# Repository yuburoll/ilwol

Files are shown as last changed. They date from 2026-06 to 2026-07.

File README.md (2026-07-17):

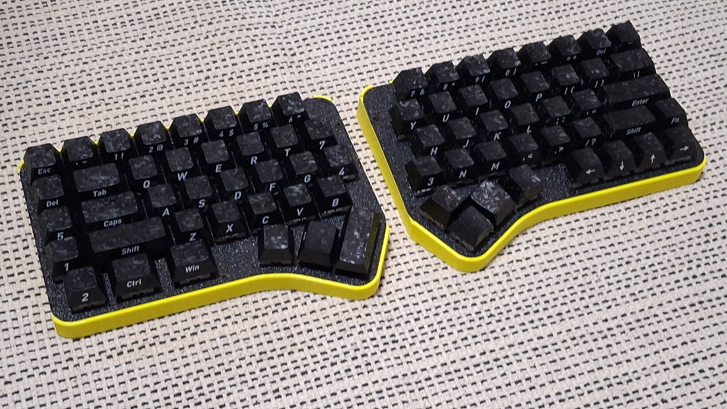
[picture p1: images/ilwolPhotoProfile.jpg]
ilwol


# ilwol
row staggered 60% hotswappable keyboard with reversible PCB, sibling of [phalwol](https://github.com/yuburoll/phalwol)

The name ilwol is January in Korean.

This keyboard has additional Y/H/B keys which positioned between keyboards, and auxilary row at left outside. You may put the keycaps from numpad.

This keyboard has hotswap-only PCB.

ilwol can change layout to followings:

- Split left shift, to ISO shaped one.(2.25u to 1.25u/1u)

- Split right shift, to HHKB inspired shape.(2.75u to 1.75u/1u)

- Split outside thumb keys(2u to 1u/1u)

- Split backspace(2u to 1u/1u)

- Can use stepped caps lock

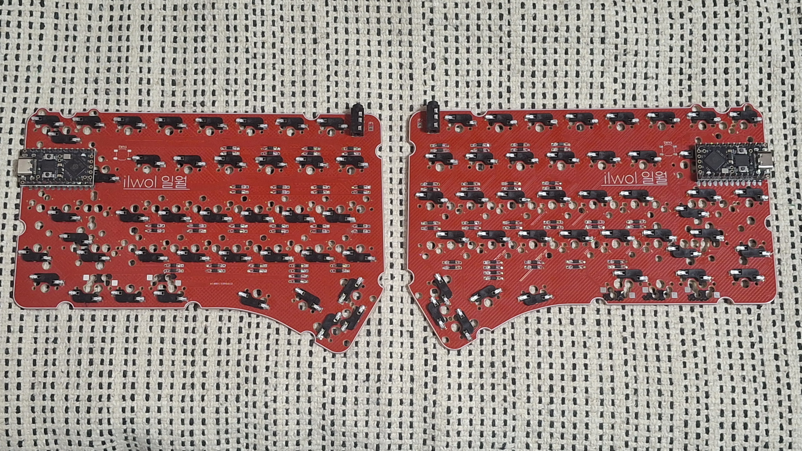
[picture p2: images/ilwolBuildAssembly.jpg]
ilwolBuildAssembly


## Preparation

- 2x pro micro form factor dev board

- 2x ilwol PCB Boards, provided from the repo

- 1x printed case sets, 2 parts total, provided from the repo (for thicker case, use "Buffed". want more? use "roundBuffed")

- 1x 1.5-1.6T keyboard plate sets, 2 parts total, provided from the repo

- 80x diodes, normally 1N4148

- 84x Kailh hotswap sockets (or compatibles)

- 16x M2x6 screws, flathead

- 2x PJ320A 1/8(3.5mm) TRRS connector (MJ-4PP-9 in other name)

- 2x 4x4x1.5mm surface mount tact switches (optional, for dev boards without reset button)

- 1x 1/8(3.5mm) TRRS cable

- 1-6x PCB Mounted 2u Keyboard Stabilizers, normally 6

- 73-78x MX Keyswitches, normally 73

- 8x 10mm bumpon stickers

- A set of Keycaps, Full-size layout, ANSI preferred.

## Differences between case variations

|Original|Buffed|RoundBuffed|Frame|
|:---:|:---:|:---:|:---:|
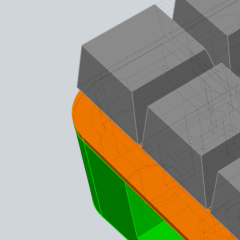
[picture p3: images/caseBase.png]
Base
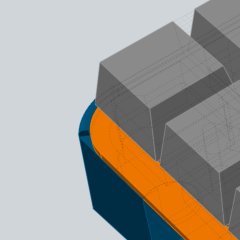
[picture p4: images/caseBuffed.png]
Buff
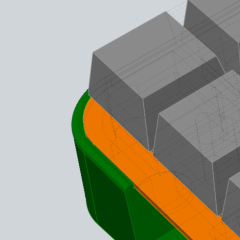
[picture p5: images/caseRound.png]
Round
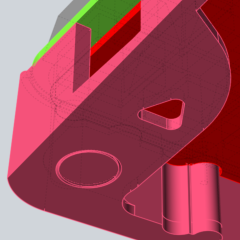
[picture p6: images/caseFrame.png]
Frame
|||||

(Frame case are lightest option for 3d print, but it is very brittle)

## Build Guides and Miscellaneous

[ilwol Build Guide](docs/buildGuide.md)

there's some notices before the build:

- You may solder all hotswaps before soldering the dev board.

- Assemble dev board with 2.5mm height pin headers on back side, assume that components side are faced up.

- Jump every jumpers on front side.

[Additional Tenting Stand](https://github.com/yuburoll/yubuGadgets/tree/main/phalilwolTentingStand)

Also take a look at the sibling, [phalwol](https://github.com/yuburoll/phalwol).

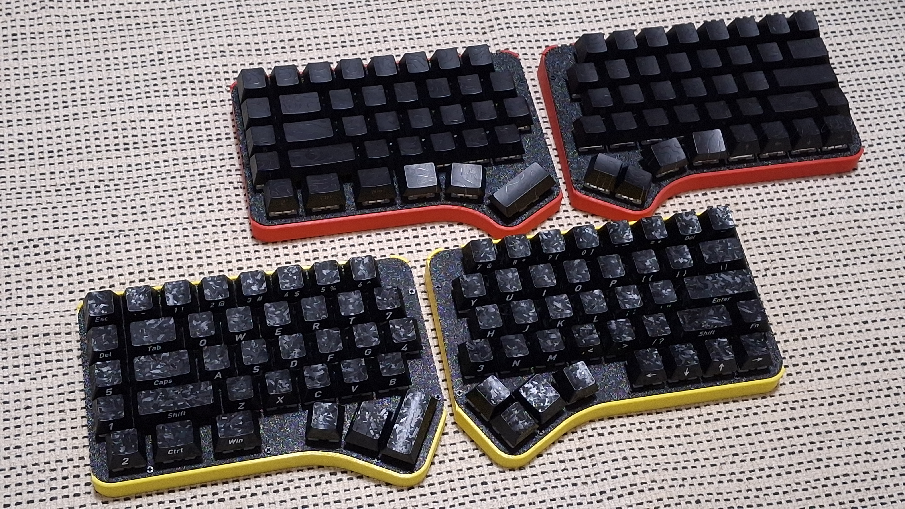
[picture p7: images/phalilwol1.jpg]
phalilwol


## Sponsorship Notice

This project is sponsored by [PCBway](https://www.pcbway.com/), where I ordered prototype PCB.

Their detailed reviewing service was fast and great. I think it will be worth the money for commercial prototyping.

And, they provide complex options (like matte coating on PCB, which pretty surprised me) for both PCB and PCBA, which are necessary for some high-end, important projects.

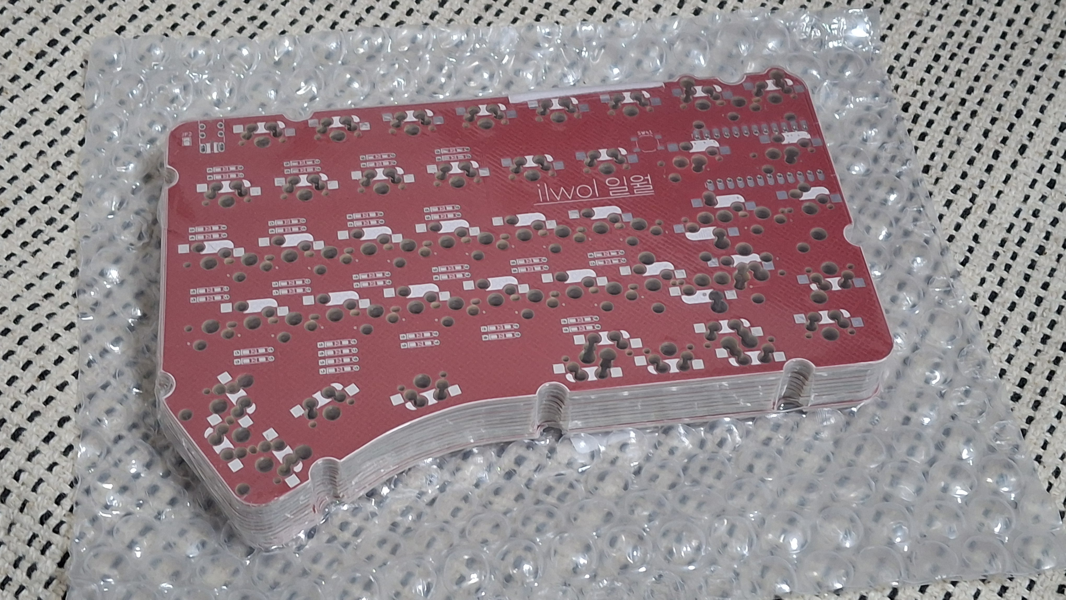
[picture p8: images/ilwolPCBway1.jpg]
ilwolPCBway1


## Licenses

all codes follow MIT license.

all designs and the hardware board follow CC BY-SA 4.0 license.

Markdown documents and photos in docs/images folder are copyrighted, all rights reserved.

If you want to make a commercial product, it would be appreciated if you sponsor some bucks for me.

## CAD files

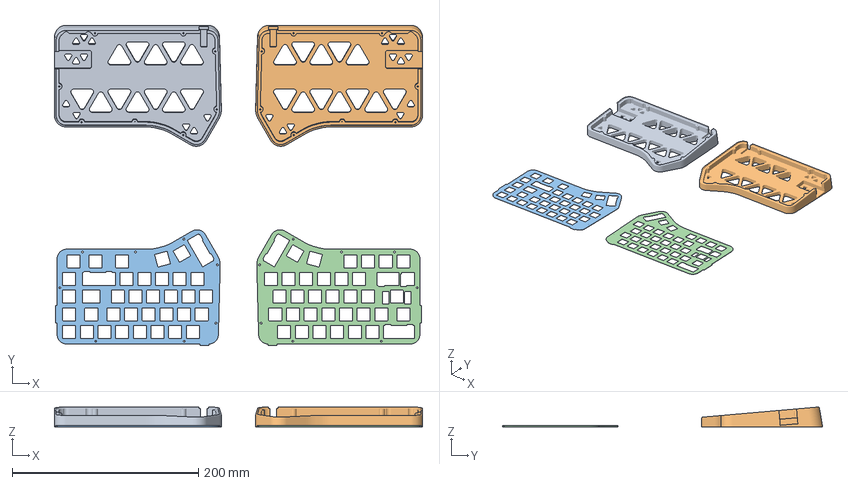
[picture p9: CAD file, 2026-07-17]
case/3mf/ilwolCaseRoundBuffed.3mf
395.5 x 344.4 x 21.5 mm
ilwolCaseRoundBuffedBridgedL.stl x 2
ilwolPlateRoundBuffedL.stl
ilwolPlateRoundBuffedR.stl

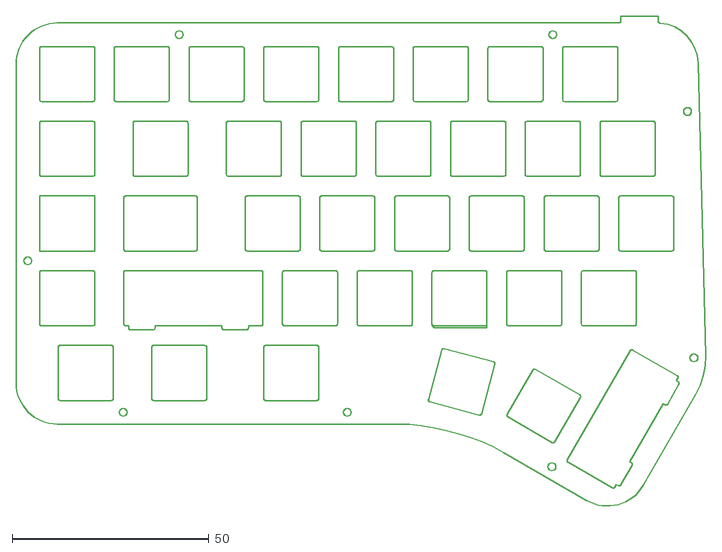
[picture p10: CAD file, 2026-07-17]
case/plateDXF/ilwolPlateBuffedL.dxf
175.4 x 126.1

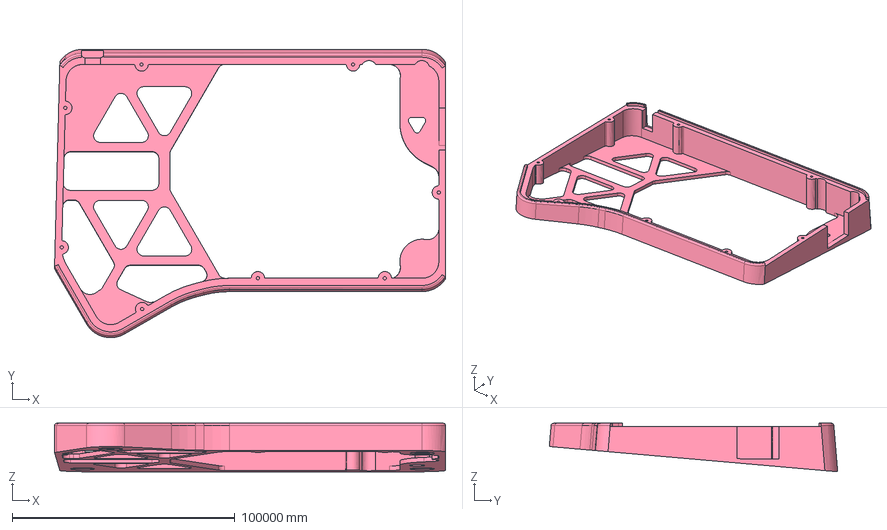
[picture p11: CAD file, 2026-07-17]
case/step/ilwolCaseFrameR.stp
175600.3 x 129534.7 x 21788.4 mm

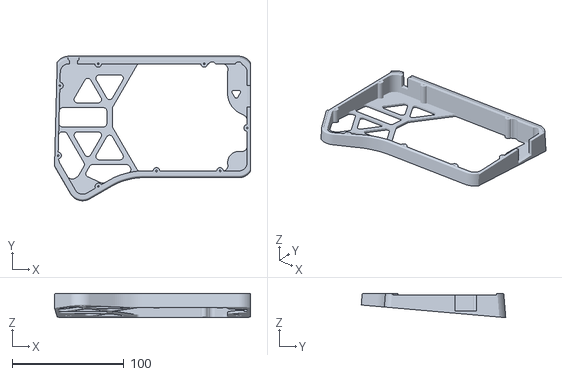
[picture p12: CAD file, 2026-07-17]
case/stl/ilwolCaseFrameBridgedR.stl
175.6 x 129.5 x 21.8

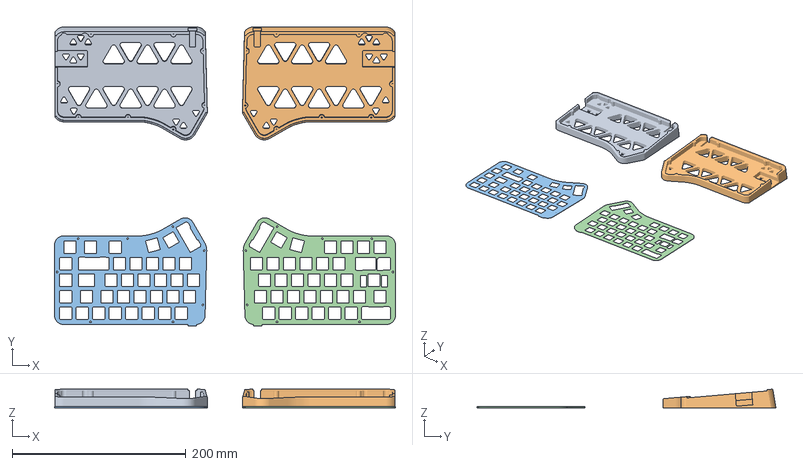
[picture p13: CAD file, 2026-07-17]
case/3mf/ilwolCaseBuffed.3mf
392.7 x 344.4 x 21.5 mm
ilwolCaseBuffedBridgedL.stl x 2
ilwolPlateBuffedL.stl
ilwolPlateBuffedR.stl

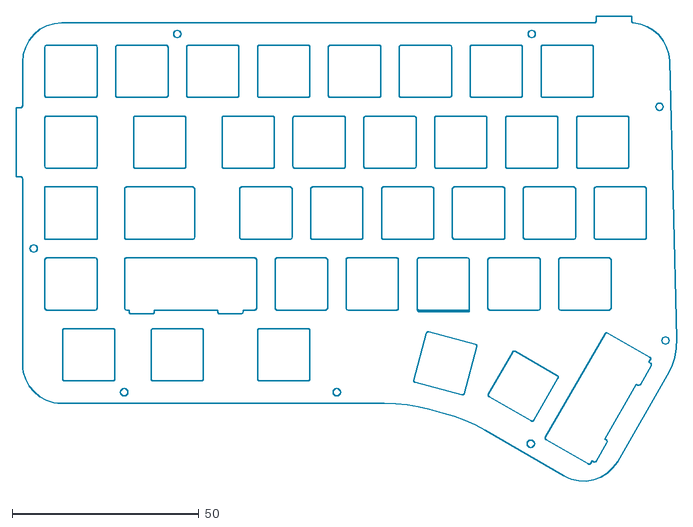
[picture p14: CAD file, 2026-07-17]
case/plateDXF/ilwolPlateRoundBuffedL.dxf
177.2 x 126.1

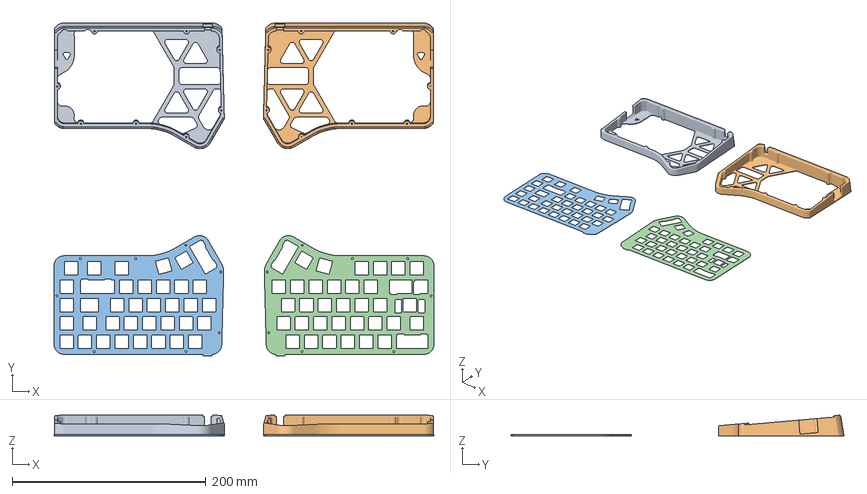
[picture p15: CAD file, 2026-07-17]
case/3mf/ilwolCaseFrame.3mf
392.7 x 344.4 x 21.5 mm
ilwolCaseFrameBridgedL.stl x 2
ilwolPlateBuffedL.stl
ilwolPlateBuffedR.stl

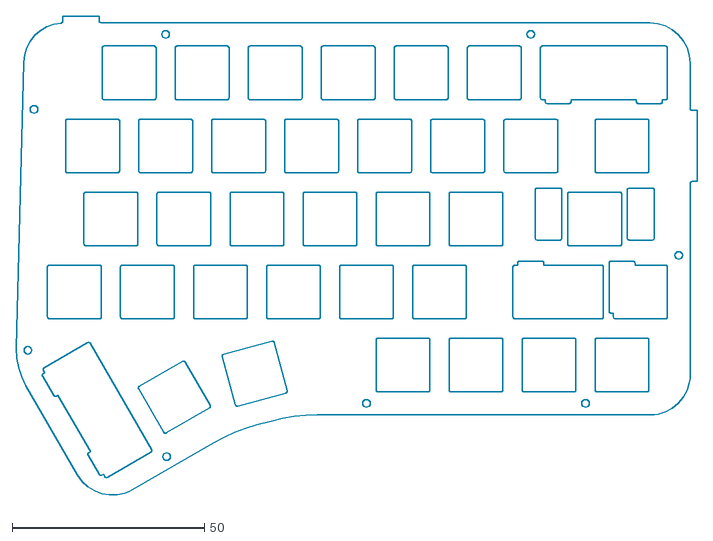
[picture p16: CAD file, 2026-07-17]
case/plateDXF/ilwolPlateRoundBuffedR.dxf
177.2 x 126.1

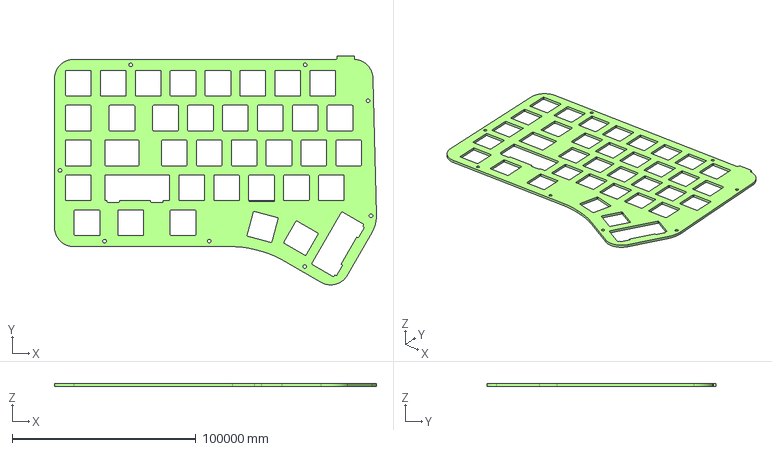
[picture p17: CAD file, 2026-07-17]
case/step/ilwolPlateBuffedL.stp
175344.4 x 124582.9 x 1500.0 mm

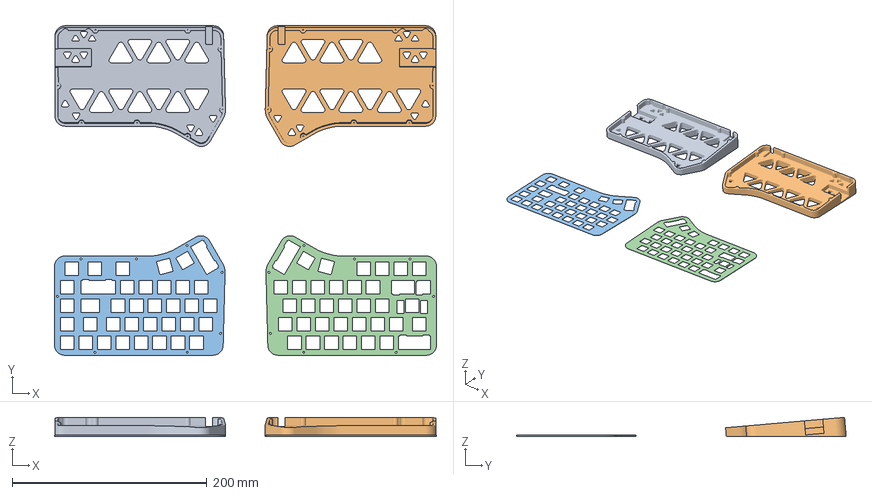
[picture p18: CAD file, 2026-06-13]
case/3mf/ilwolCase.3mf
392.7 x 338.8 x 19.9 mm
ilwolCaseBridgedL.stl x 2
ilwolPlateL.stl
ilwolPlateR.stl

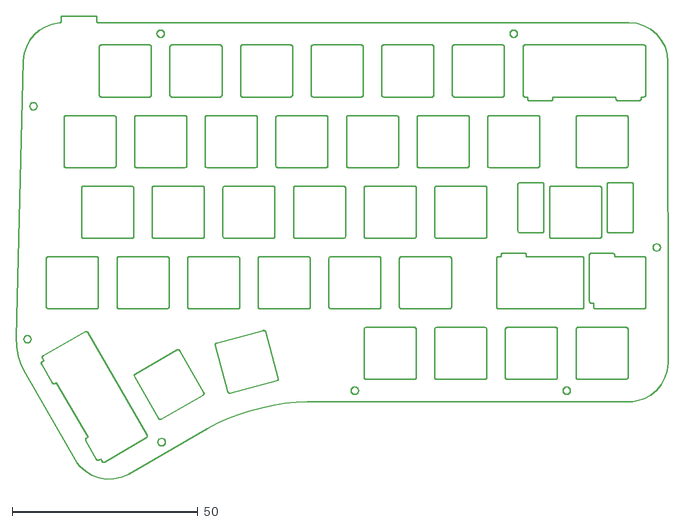
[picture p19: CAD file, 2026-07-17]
case/plateDXF/ilwolPlateBuffedR.dxf
175.4 x 126.1

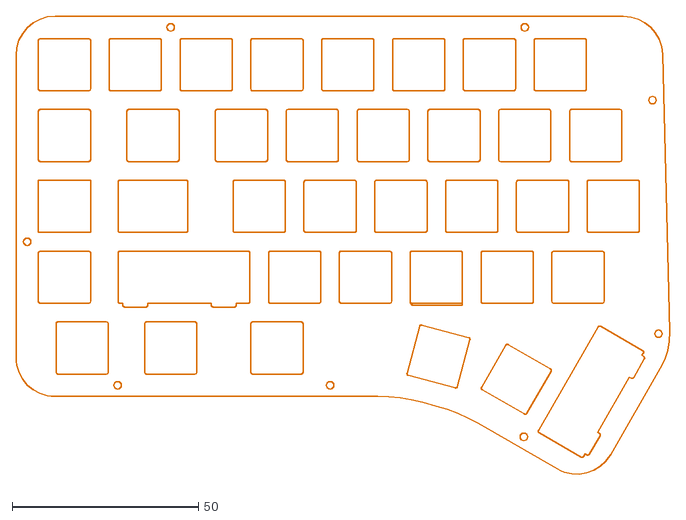
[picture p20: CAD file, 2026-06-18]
case/plateDXF/ilwolPlateL.dxf
175.4 x 124.3

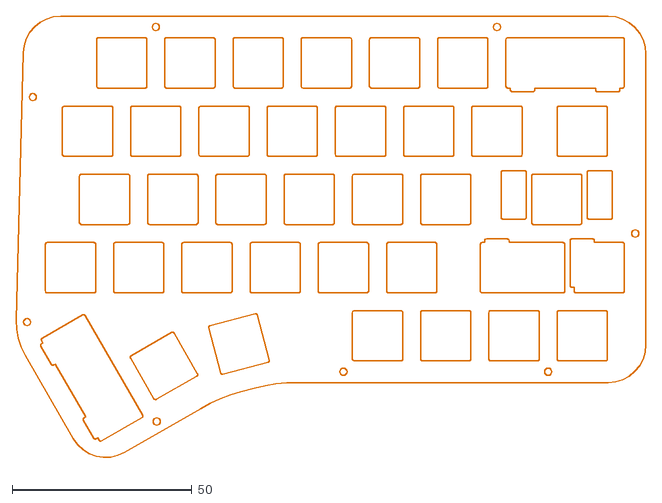
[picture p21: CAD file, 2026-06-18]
case/plateDXF/ilwolPlateR.dxf
175.4 x 124.3

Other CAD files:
case/step/ilwolCaseFrameL.stp
case/stl/ilwolCaseFrameBridgedL.stl
case/step/ilwolPlateRoundBuffedR.stp
case/step/ilwolPlateRoundBuffedL.stp
case/step/ilwolPlateBuffedR.stp
case/step/ilwolCaseBuffedL.stp
case/step/ilwolCaseBuffedR.stp
case/step/ilwolCaseL.stp
case/step/ilwolCaseR.stp
case/step/ilwolCaseRoundBuffedL.stp
case/step/ilwolCaseRoundBuffedR.stp
case/step/ilwolPlateL.stp
case/step/ilwolPlateR.stp
case/stl/ilwolCaseFrameL.stl
case/stl/ilwolCaseFrameR.stl
case/stl/ilwolPlateBuffedL.stl
case/stl/ilwolPlateBuffedR.stl
case/stl/ilwolPlateL.stl
case/stl/ilwolPlateR.stl
case/stl/ilwolPlateRoundBuffedL.stl
case/stl/ilwolPlateRoundBuffedR.stl

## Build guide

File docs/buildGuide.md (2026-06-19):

# Build Guide
this is build guide for ilwol.

the build guide contains photo of prototype version. newest version have following differences:

- the corner screws of outside top are moved 1u inside, so do the PCB design.

- lower pinky modifier keys are not changeable. as black marked in prototype PCB

This documents are translated by generative AI, so there can be some misleading texts.

### Additional Resources
[**Soldering Tips**](solderingTip.md)

# PCB Preparation
Prepare two PCBs for the ilwol. Since these are reversible PCBs, be careful to place components on different sides for each board.

The side where components will be placed is treated as the back, and the side without components is treated as the front. **All components go on back side only, so please be careful when soldering.**

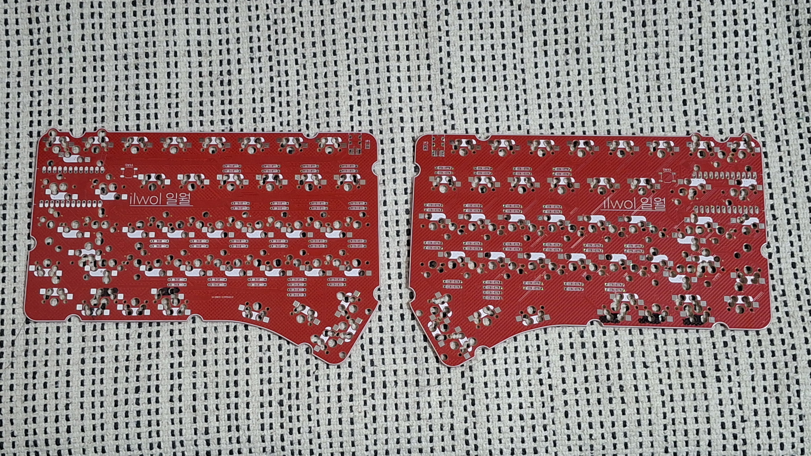
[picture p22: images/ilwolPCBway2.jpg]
ilwolPCBway2


# Soldering the Diodes
Solder the diodes. The photos show SMD diodes being used, but THT diodes can also be used.

In the photo, the hot-swap sockets are soldered first, but I recommend soldering the diodes first.

When using SMD diodes, first apply a solder blob to one side of the pad with a soldering iron, as shown in the following photos.

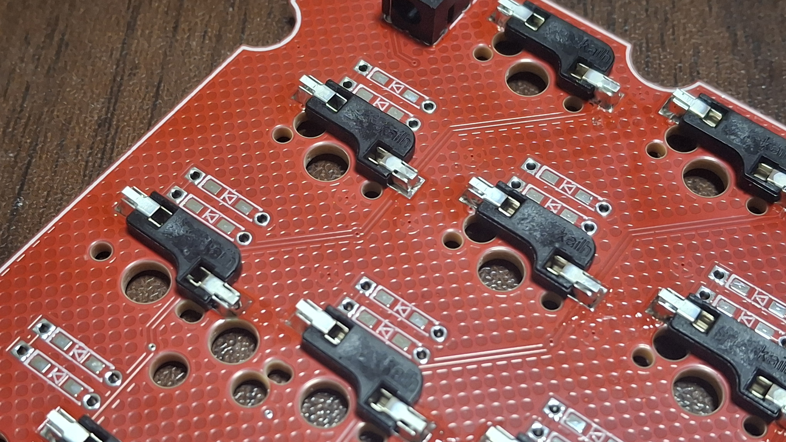
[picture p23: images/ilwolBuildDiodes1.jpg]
ilwolBuildDiodes1

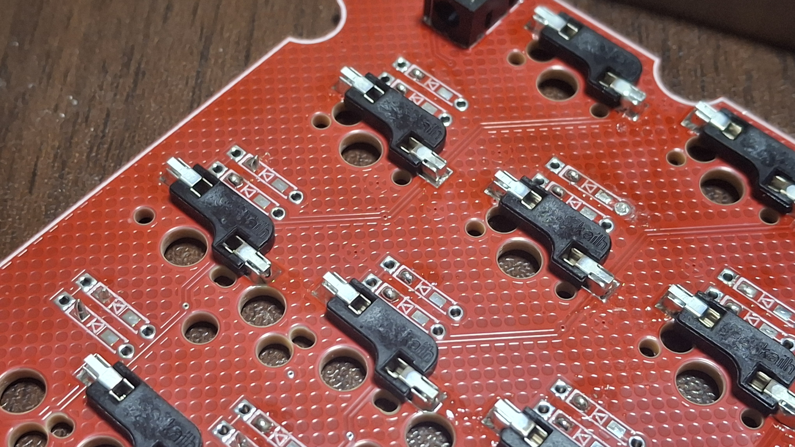
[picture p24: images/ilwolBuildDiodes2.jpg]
ilwolBuildDiode2


Reheat the solder blob with the iron to melt it, align the diode in the correct orientation and place it in position, then remove the iron.

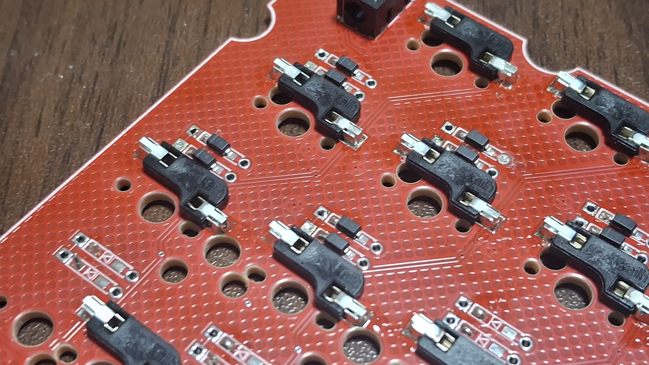
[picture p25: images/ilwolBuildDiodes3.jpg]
ilwolBuildDiode3


Once it is seated properly, solder the opposite leg.

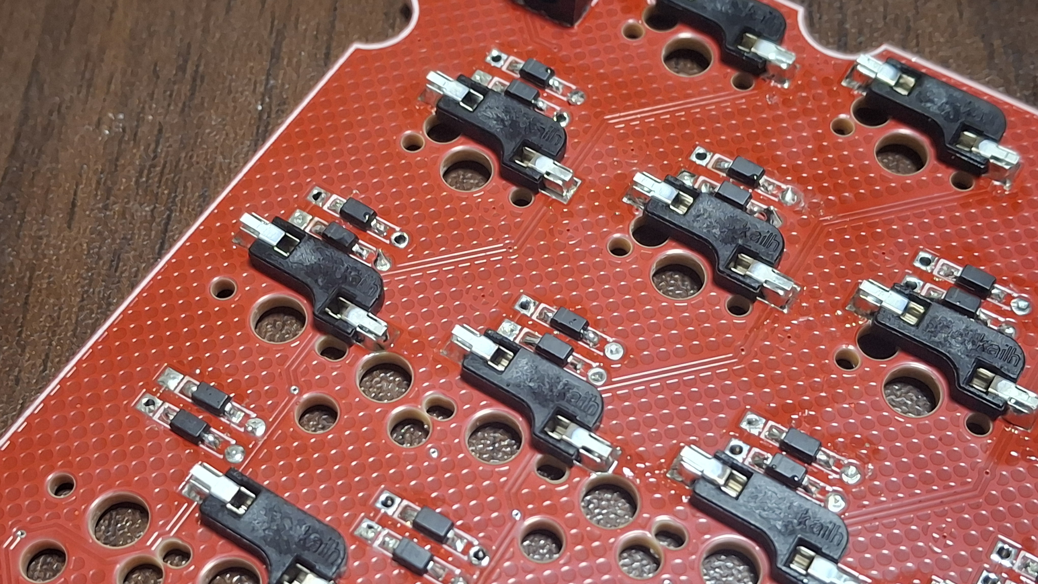
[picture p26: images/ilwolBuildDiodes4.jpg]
ilwolBuildDiode4


# Soldering the Hot-swap Sockets
Solder the hot-swap sockets. The process is largely the same as soldering the diodes and LEDs.

As before, apply a solder blob to one side of the pad, reheat the blob to melt it, place the component and hold it in position, remove the iron, then solder the opposite leg.

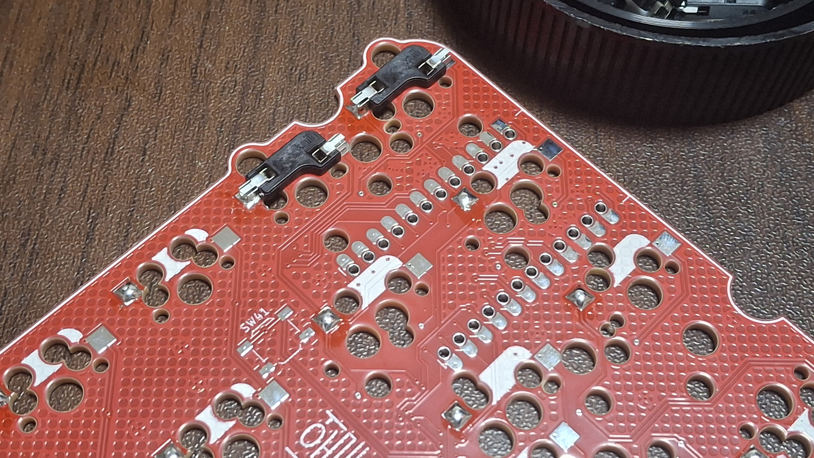
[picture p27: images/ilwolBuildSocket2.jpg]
ilwolBuildSocket2

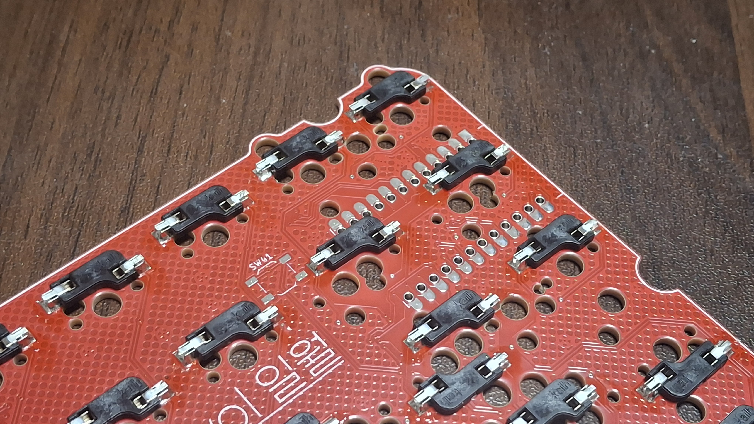
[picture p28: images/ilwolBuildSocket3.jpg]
ilwolBuildSocket4


# Soldering the TRRS Jack and the Jumper
Refer to the following photos to identify where the TRRS jack will be placed. The jack will be placed on back side, so you may solder that on front side.

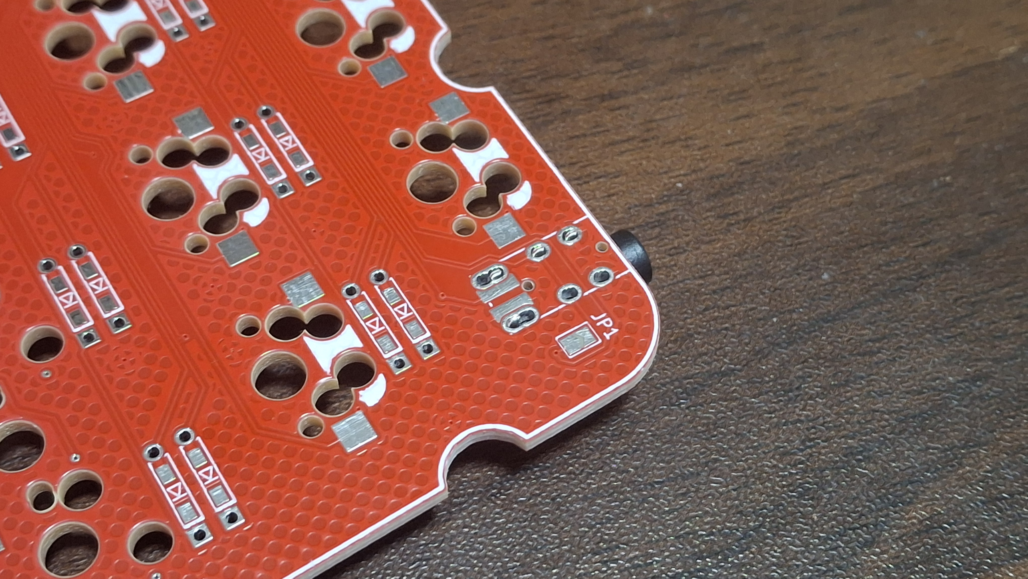
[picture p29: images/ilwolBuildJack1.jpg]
ilwolBuildJack1

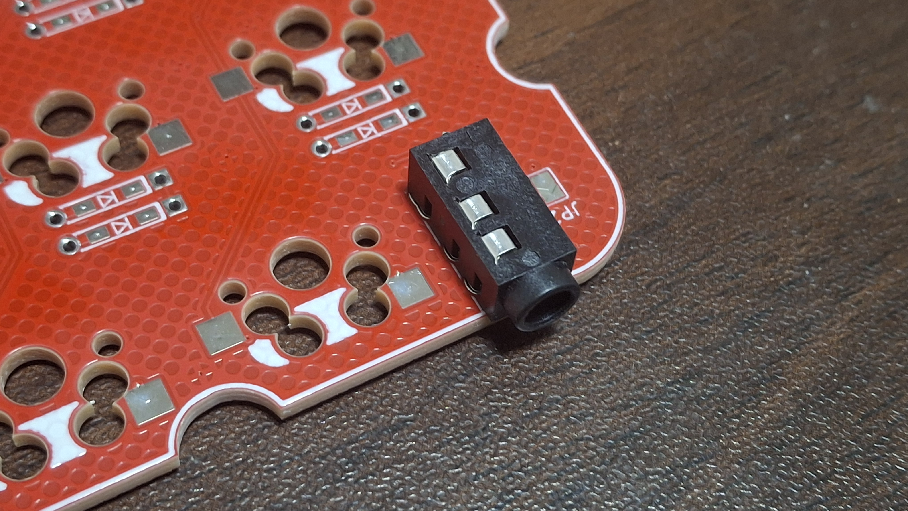
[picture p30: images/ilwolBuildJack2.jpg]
ilwolBuildJack2


Solder the TRRS jack. When soldering the Tip and Sleeve pins, also bridge them to the adjacent pads as shown in the photo.

And, On the front side seen when soldering the jack, bridge the jumpers located aside. Apply enough solder so that a blob forms on top.

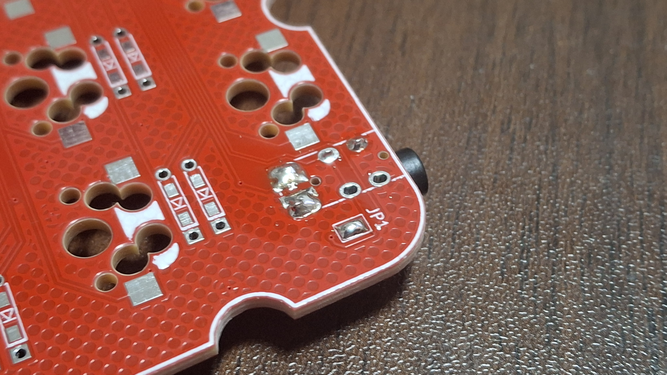
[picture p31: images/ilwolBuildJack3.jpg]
ilwolBuildJack3


# Soldering the Dev Board
First, check the header pins on the provided Pro Micro dev board. The outermost row of header pins past 5V is not needed, so trim them off.

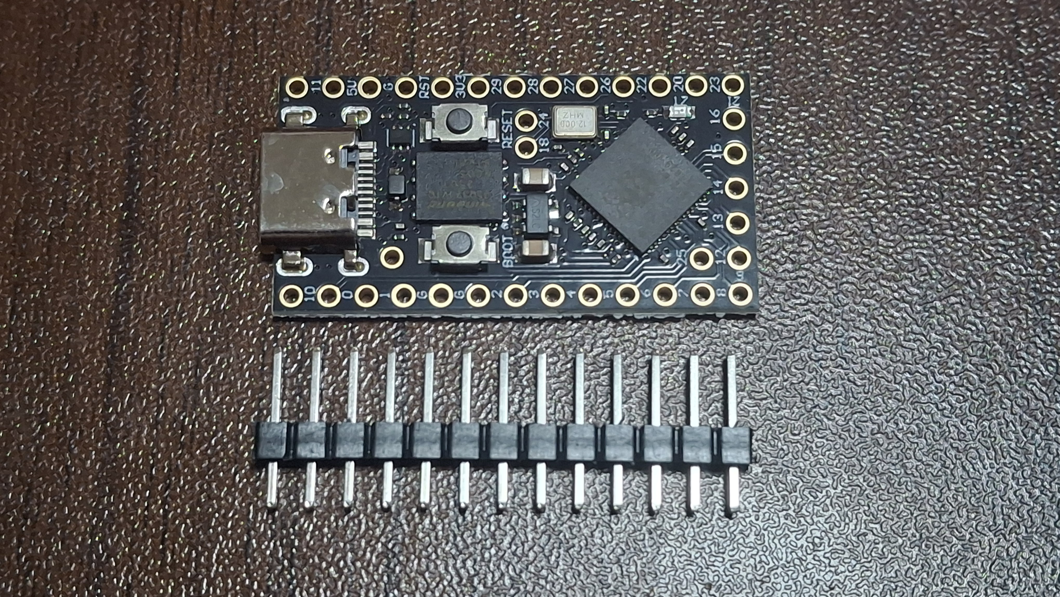
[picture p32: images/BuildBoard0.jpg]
BuildBoard0

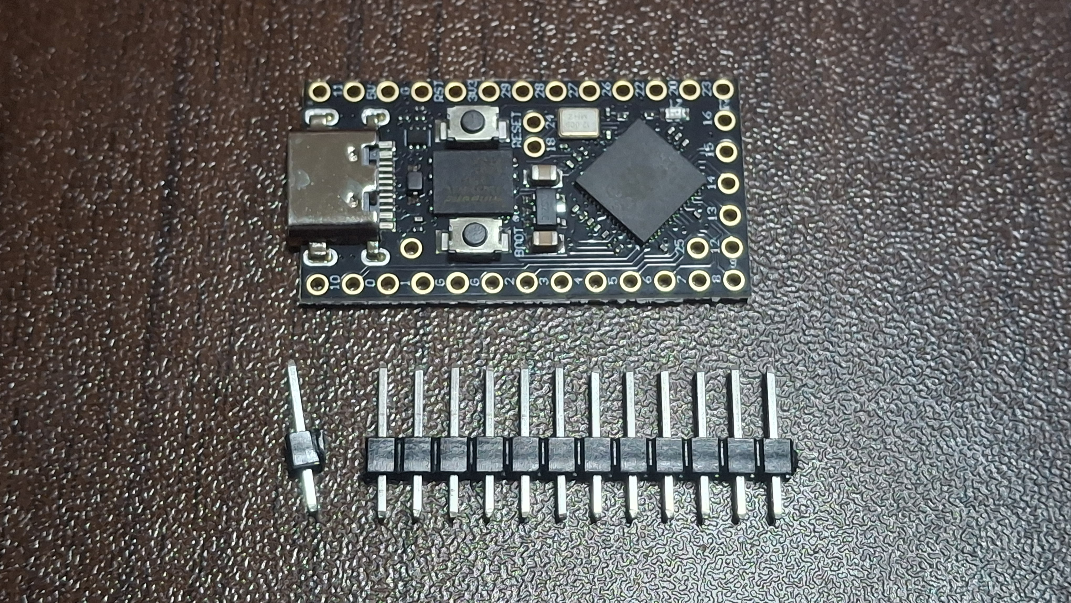
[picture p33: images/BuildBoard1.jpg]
BuildBoard1


Insert the header pins starting from 5V, align them, and solder the dev board. When soldering, make sure the components face upward as shown in the photo.

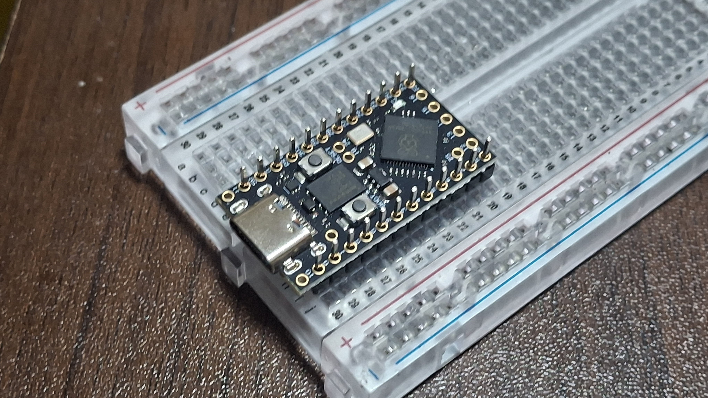
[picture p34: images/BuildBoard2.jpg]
BuildBoard2

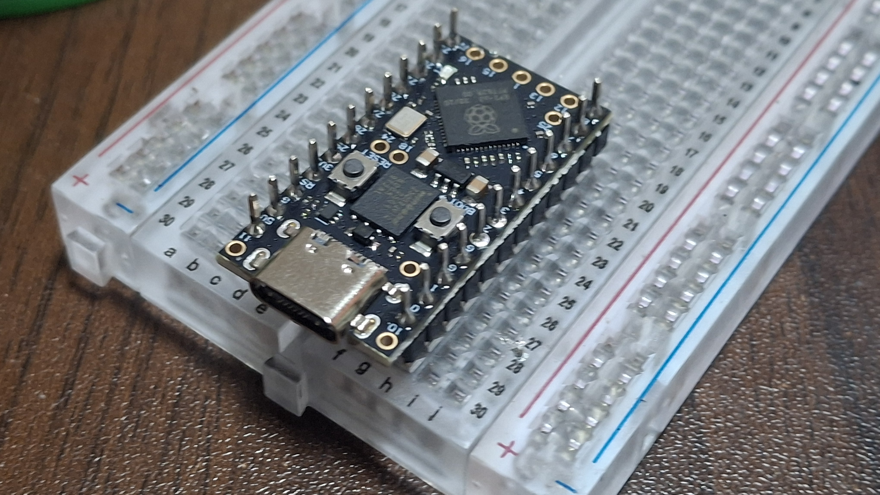
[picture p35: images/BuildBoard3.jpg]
BuildBoard3


Place the dev board with the soldered header pins on top of the already-soldered hot-swap sockets. Press down firmly to ensure a tight fit.

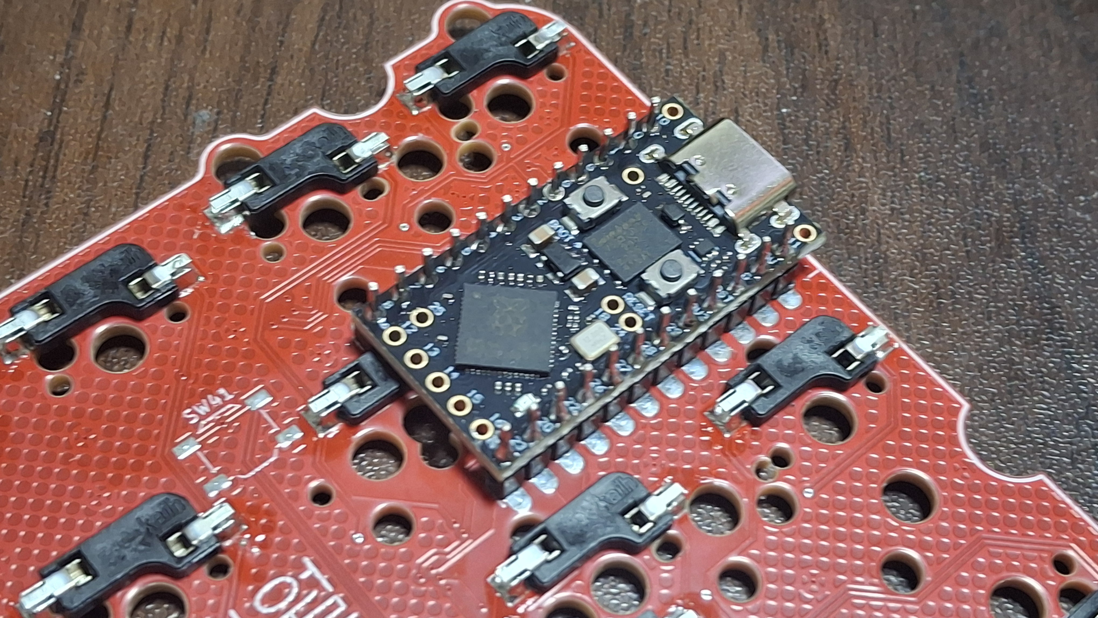
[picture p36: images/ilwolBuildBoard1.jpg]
ilwolBuildBoard1

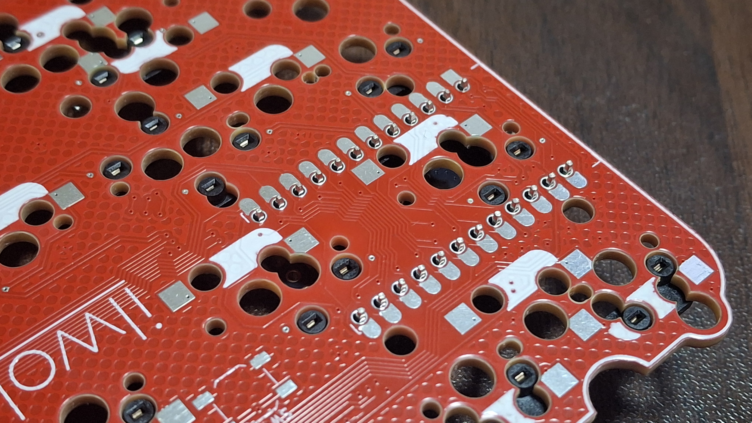
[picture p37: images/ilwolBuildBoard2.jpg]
ilwolBuildBoard2


Just like when soldering the TRRS jack pins, bridge the header pins to the adjacent pads as if soldering jumpers. Since a large amount of solder is used, there is a risk of bridging with flux, so be sure to clean the area with alcohol after soldering.

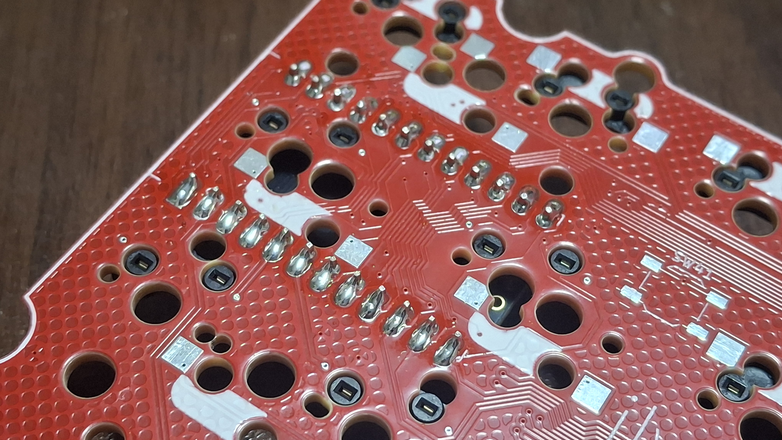
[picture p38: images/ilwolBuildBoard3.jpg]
ilwolBuildBoard4


# Check PCB and flash firmware before Assembly
The finished PCBs looks like a following image.

ilwolBuildAssembly

If you're a keyboard enthusiast, I'd recommend installing stabilizers at keycap positions 2u or larger, as shown in the following photo.

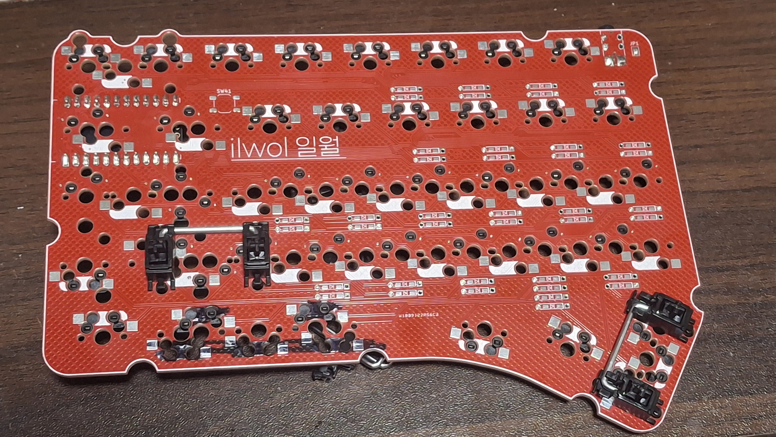
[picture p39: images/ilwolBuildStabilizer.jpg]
ilwolBuildStabilizer


Also, please flash the firmware before assembling the case.

For the RP2040 promicro, hold down the Boot button on the development board while connecting the USB, then drop the .uf2 file onto the removable disk that appears.

For the ATmega32U4 promicro, load the firmware .hex in your flashing tool (e.g., QMK Toolbox). Then, with the USB connected, briefly short RST and GND with a conductor, or solder a 4x4x1.5mm tactile switch to those pads and press it. The Caterina bootloader will activate and the tool will flash the firmware.

# Assembly
First, assemble plate and switches together with proper direction, and assemble PCB on it.

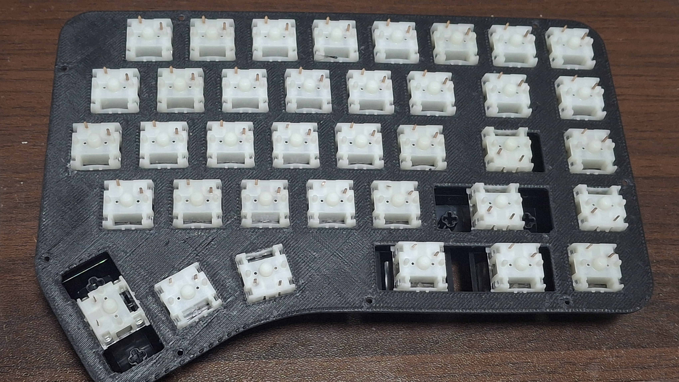
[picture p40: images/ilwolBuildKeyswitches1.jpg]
ilwolBuildKeyswitches1

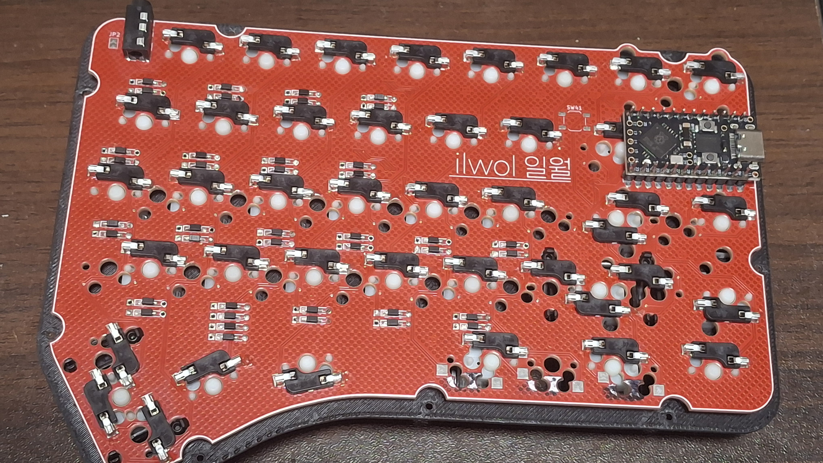
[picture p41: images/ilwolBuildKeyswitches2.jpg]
ilwolBuildKeyswitches2


Place the plate assembly over the case and fasten it with screws at eight points per side to complete the build. also, you may add four bumpons on the bottom of the case.

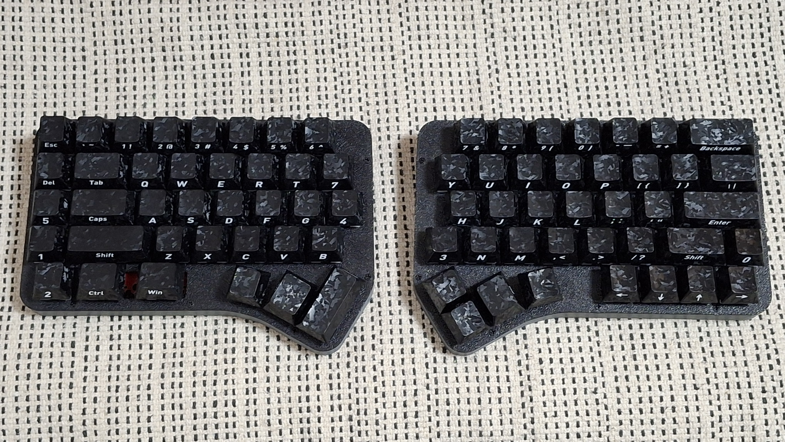
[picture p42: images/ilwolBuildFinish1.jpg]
ilwolBuildFinish1

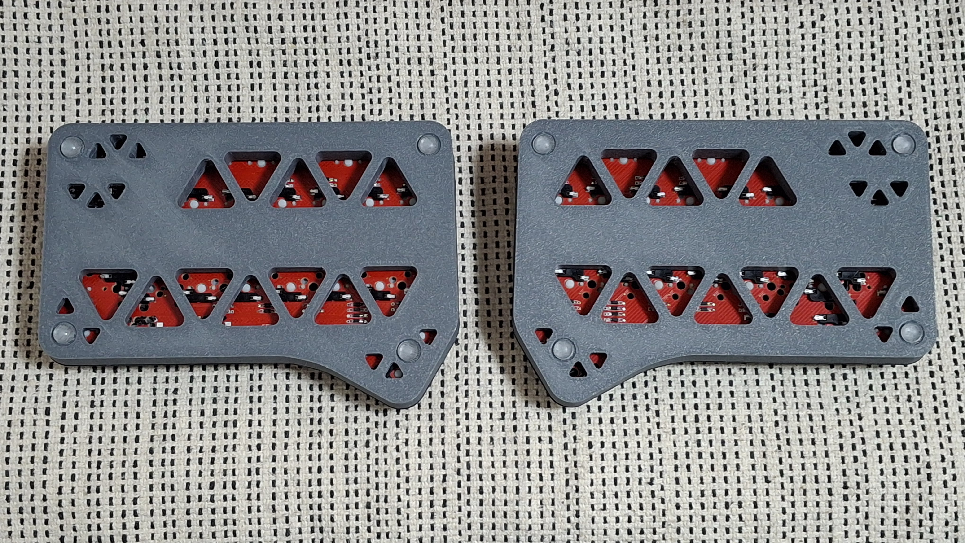
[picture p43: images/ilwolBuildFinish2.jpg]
ilwolBuildFinish2


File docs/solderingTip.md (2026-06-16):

# Soldering Tips

A collection of soldering advice and tips.

This documents are translated by generative AI, so there can be some misleading texts.

## Supplies

- Soldering iron & stand: A chisel tip is the most convenient to work with. I recommend getting one that can maintain a temperature of at least 400–500°C.

- Solder: Choose between leaded and lead-free solder. Leaded solder is less stressful to work with, but it is not good for your health.

- Solder paste (flux): **The god of soldering.** If your solder joints are not turning out well, frequently wipe and coat the iron tip with paste flux.

- Damp sponge/paper towel, or a tip cleaner (brass wool): Used to wipe residual solder off the iron tip.

- Solder wick or solder sucker: Used to fix bad solder joints. For beginners, solder wick is recommended.

- Flush cutters: Used to clip the legs of THT diodes after soldering.

## Ventilate Your Workspace

The metal fumes from melting solder are a concern, but they are actually quite minimal. The bigger issue is the smoke from the rosin flux inside the solder burning and melting — it is quite harmful and produces a lot of smoke. It is very bad for your health, so ventilate the area, or if ventilation is not possible, make sure to use an air purifier. Always wear a mask.

## Double-Check Before Soldering Components

It is easier to prevent a bad solder joint than to fix one. To correct a solder joint, apply flux to solder wick and press it against the joint with the iron, or apply a small amount of flux to the iron tip, melt the solder, and simultaneously press a solder sucker against it to absorb the solder.

## Apply Flux If Solder Is Not Sticking

Melt flux onto the iron tip to coat it, or use a flux pen to apply it directly to the PCB pads.

## Touch the Iron First When Starting, Remove It Last When Finishing

Place the iron on the pad first to preheat the PCB and component, then melt the solder onto the joint. When finishing, remove the solder first, then remove the iron last.

## Use Masking Tape to Temporarily Hold Components

For components like sockets, securing them with masking tape before soldering is helpful. This is especially important when you need to flip the board over, as components can be difficult to hold in place.

## Clean the Flux After Soldering

Scrub the remaining flux and any areas prone to short circuits thoroughly using a toothbrush dipped in isopropyl alcohol. You can also spray alcohol on the board, scrub with a toothbrush, and let it dry. Keyboard key inputs may work fine with residual flux, but encoders and analog inputs are more susceptible to issues caused by flux bridging.

## If Something Goes Wrong, Reflow and Clean

Problems can arise from cold joints, insufficient solder, excess solder bridging neighboring pads, or electrical interference from flux residue. In most cases, reflowing the solder joint and cleaning the flux will resolve the issue.

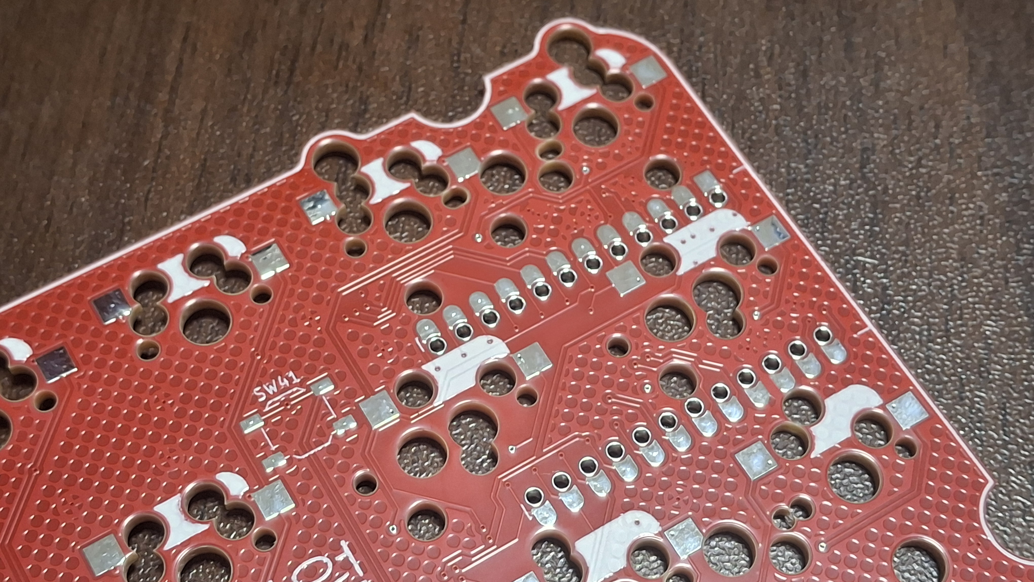
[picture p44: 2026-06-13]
images/ilwolBuildSocket1.jpg

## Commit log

2026-05-22 first upload
    [ilwol.kicad_sch]
2026-05-22 update pcb
2026-05-29 create gerber
    [ilwol-B_Mask.gbr, ilwol-B_Paste.gbr, ilwol-B_Silkscreen.gbr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]
2026-06-02 shiftable modifier switch to fixed one
2026-06-05 refresh build and gerber
    [ilwol-B_Mask.gbr, ilwol-B_Paste.gbr, ilwol-B_Silkscreen.gbr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]
2026-06-05 update TRRS hole to larger one
    [ilwol-B_Mask.gbr, ilwol-B_Paste.gbr, ilwol-B_Silkscreen.gbr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]
2026-06-05 fix colliding part of case
2026-06-05 edit pcb point for fixed case
    [ilwol-B_Mask.gbr, ilwol-B_Paste.gbr, ilwol-B_Silkscreen.gbr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]
2026-06-05 fix hole position
2026-06-11 add buffed case
2026-06-13 case upload
    [ilwolCase.3mf, ilwolCaseBuffed.3mf, ilwolCaseBuffedL.stp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]
2026-06-18 change fillet of case for cnc
    [ilwolCaseBuffedL.stp, ilwolCaseBuffedR.stp, ilwolCaseL.stp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]
2026-06-18 add plate stp file
    [ilwolPlateL.stp, ilwolPlateR.stp]
2026-06-18 Create external footprint license.txt
2026-06-19 add case chopped varient - from buffed
    [ilwolCaseChopped.3mf, ilwolCaseChoppedL.stp, ilwolCaseChoppedR.stp]
2026-06-19 changed name for clearance with phalwol
    [ilwolCaseBuffed.3mf, ilwolCaseBuffedL.stp, ilwolCaseBuffedR.stp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]
2026-06-19 add case varient check
2026-06-19 case image size unify
2026-07-09 add caseFrame variation
    [ilwolCaseFrame.3mf, ilwolCaseFrameBridgedL.stl, ilwolCaseFrameBridgedR.stl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]
2026-07-09 update for weakest part
    [ilwolCaseFrame.3mf, ilwolCaseFrameBridgedL.stl, ilwolCaseFrameBridgedR.stl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]
2026-07-09 frame reinforcement for weakest part(again)
    [ilwolCaseFrameBridgedL.stl, ilwolCaseFrameBridgedR.stl, ilwolCaseFrameL.stl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]
2026-07-17 update CaseFrame to tentable and add more plate options
    [ilwolCaseBuffed.3mf, ilwolCaseFrame.3mf, ilwolCaseFrameBridgedL.stl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]
